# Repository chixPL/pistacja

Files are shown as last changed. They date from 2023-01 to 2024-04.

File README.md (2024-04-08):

# Pistacja
## A web-based weather station built with Raspberry Pi and Python.

<p align="center">
    pistacja-logo
</p>

🇵🇱 Wersja po polsku jest dostepna [tutaj](../master/README_pl.md).

*The name is a wordplay in Polish - Pi because it's built with Raspberry Pi and stacja (station). Together they make pistachio.*

## Features
* Current weather conditions (temperature, wind speed anddirection, humidity, pressure, etc.)
* History of the weather at given dates
* Statistical data - charts and graphs for the weather this week and this month
* Server info: Neofetch, uptime

Loosely based on [this guide](https://projects.raspberrypi.org/en/projects/build-your-own-weather-station/0), however due to hardware differences I wrote a lot of the code myself.

## Requirements
* Raspberry Pi (tested on Model 3 B V1.2). Internet connection required.
* Latest version of Raspbian with Python 3.7+ installed
* MCP3008 ADC converter
* Two Ethernet outlets or breakout boards
* Barometer and altimeter (built with Pololu LPS25H)
* Anemometer, rain gauge (built with SparkFun Weather Meter Kit)
* Temperature and humidity sensor (built with Aosong AM2301)
* 4.7kΩ resistor

## Installation
1. Build the weather station according to the schema below.
2. Clone this repository to your Raspberry Pi
3. Enable I2C and SPI in `raspi-config`. Reboot.
4. Install the required Python packages: `pip3 install -r requirements.txt`
5. Set the database config in .db to point to an external server
6. Run the server: `python3 main.py`
7. Paste the frontend directory to your web server's root directory and set db_connect.php to point to the same server
8. Open the website in your browser and enjoy!

### Build schematic
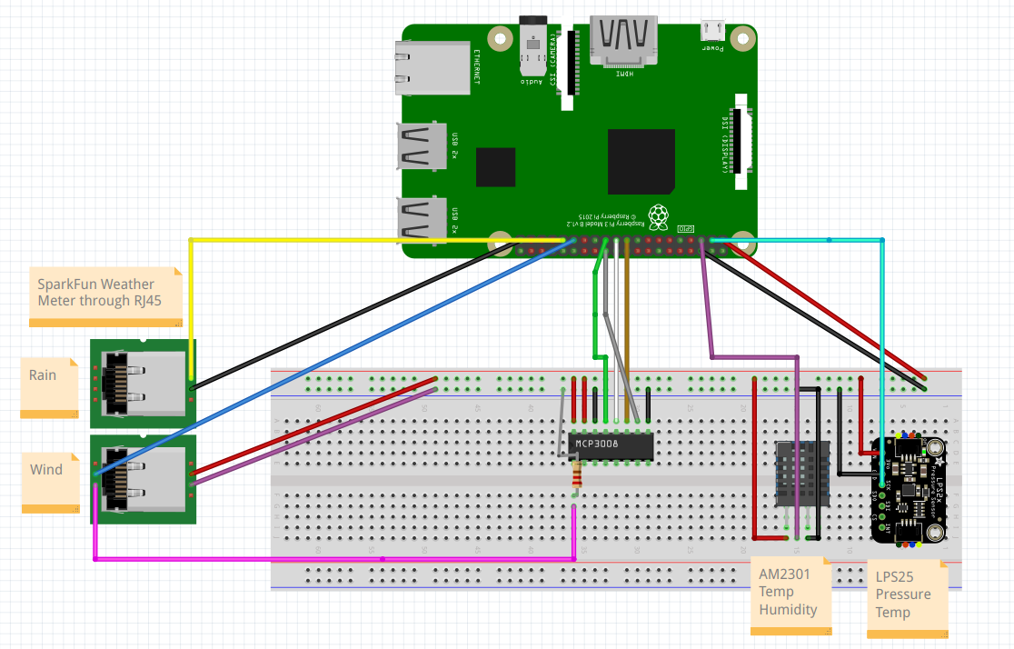
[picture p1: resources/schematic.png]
schematic


## Screenshots
### Build
#### Without case
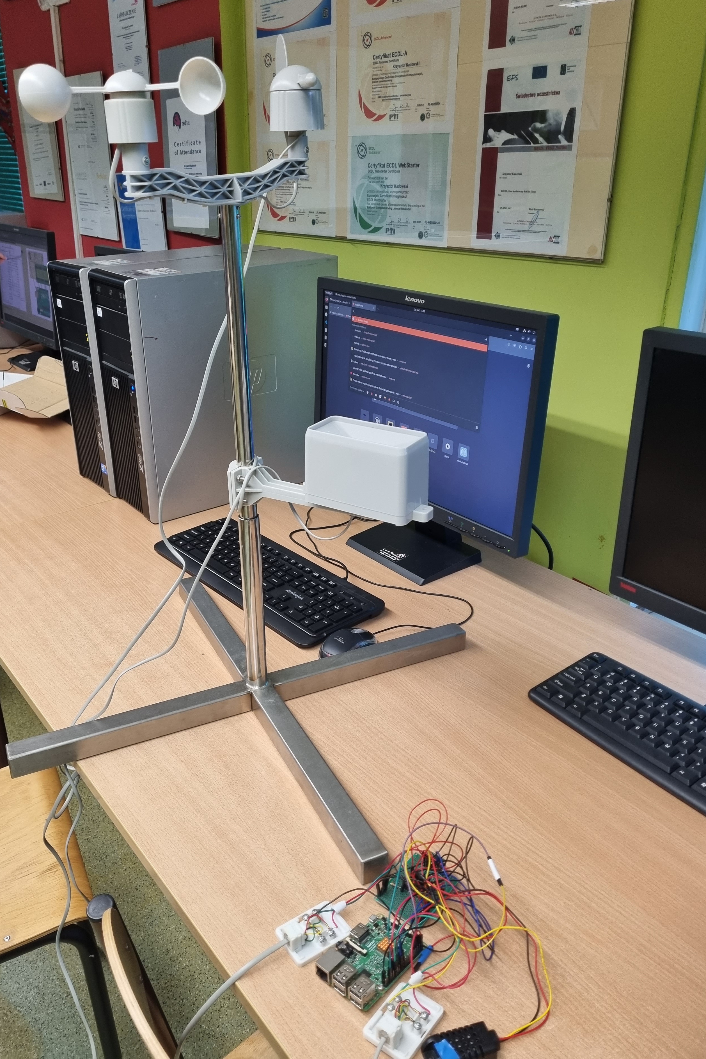
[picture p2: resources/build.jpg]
build-nocase

When properly laid out, the case dimensions would be around 17x15x7cm. I left enough wiggle room to account for longer wires and/or nonstandard peripherals
#### With case
[TBD]

### Backend
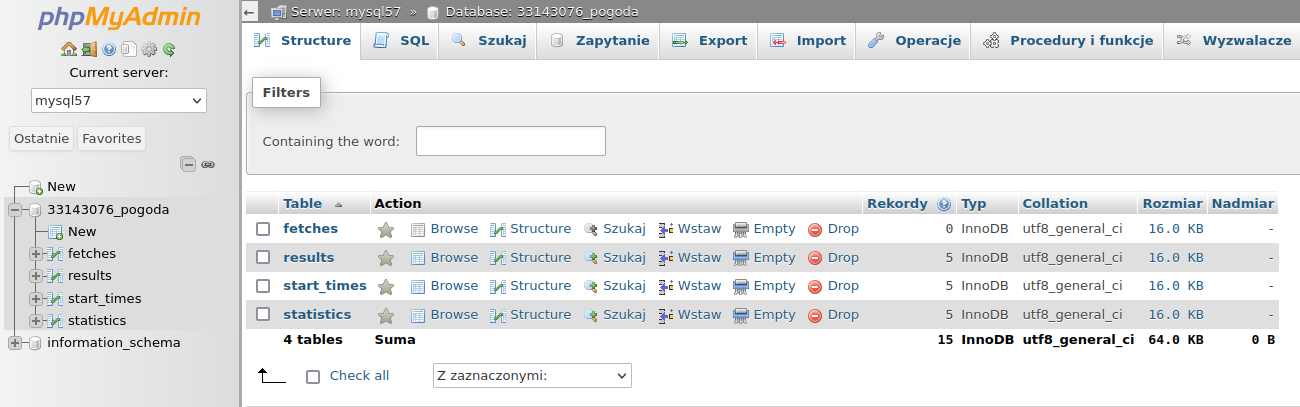
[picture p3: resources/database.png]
database

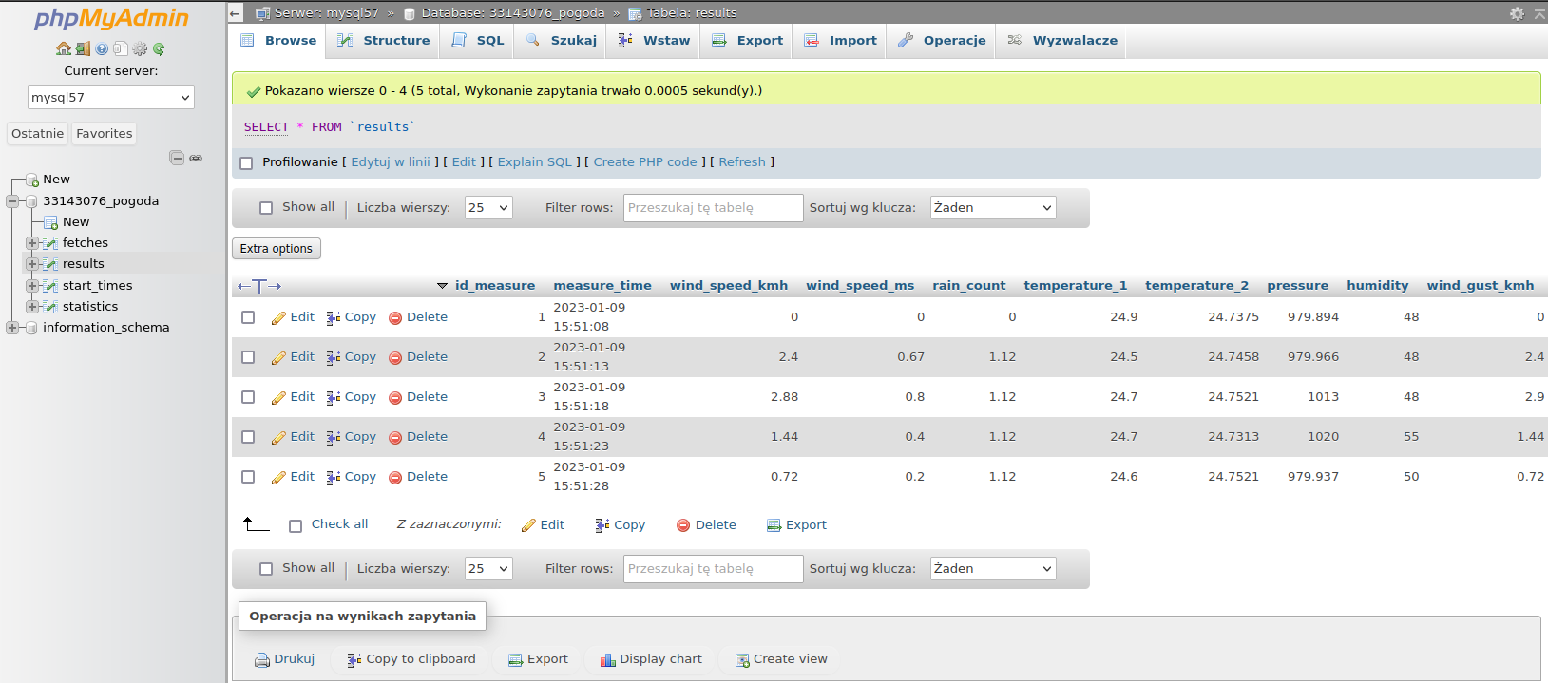
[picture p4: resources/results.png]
results


### Frontend
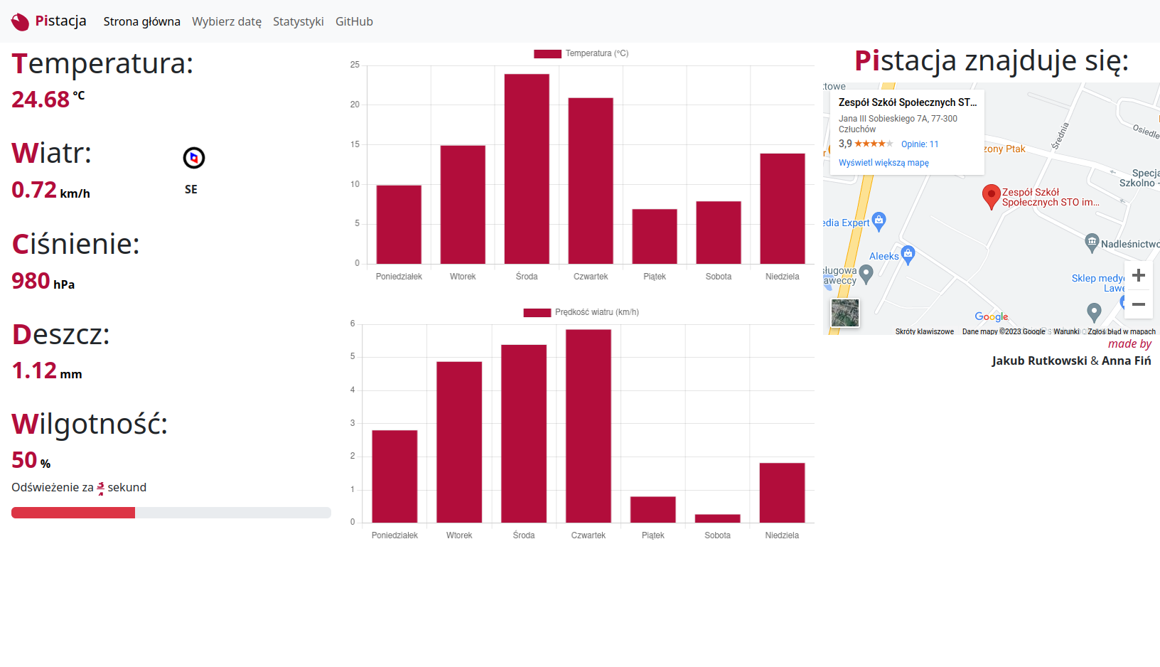
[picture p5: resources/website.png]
website


## License and Credits
This project is licensed under the GPLv3 license - see the LICENSE.md file for details.
Thanks to the Raspberry Pi Foundation for the guide.
Schematics made in Fritzing.

Made by Jakub Rutkowski (x5px) 2023

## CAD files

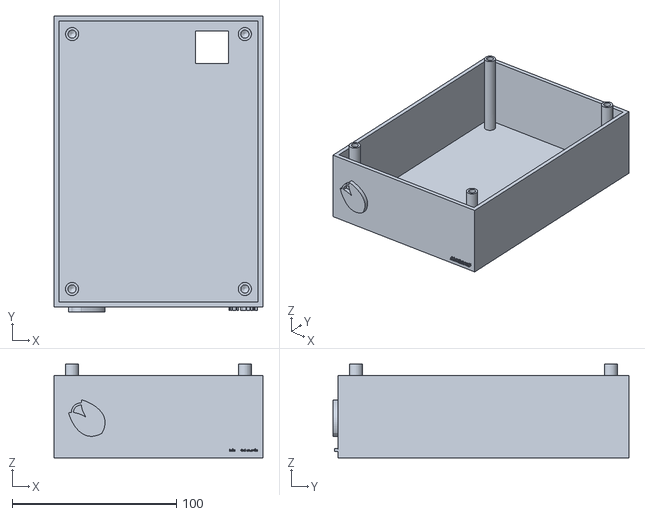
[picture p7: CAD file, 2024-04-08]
Model 3D/STL/Pistacja.stl
127.0 x 180.0 x 57.0

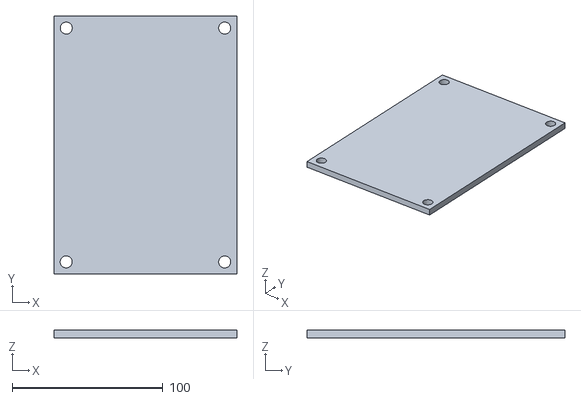
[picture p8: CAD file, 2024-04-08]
Model 3D/STL/Pistacja Wieko.stl
121.0 x 171.0 x 5.00

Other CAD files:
Model 3D/Fusion360/Pistacja Wieko.f3d
Model 3D/Fusion360/Pistacja.f3d

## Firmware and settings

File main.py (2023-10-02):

"""
[PL]
Pistacja - stacja pogodowa za pomocą Raspberry Pi
[EN]
Pistacja - a weather station with Raspberry Pi

Losto 2022
by: Jakub Rutkowski & Ania Fiń
[EN]
"""

# Standard imports
import math
import time
import atexit
import statistics

# Requirements (pip install -r requirements.txt)
import board
from gpiozero import Button, MCP3008 # Button (on/off signal detector) - Sparkfun Weather Meter, MCP3008 - ADC converter
import adafruit_dht # Barometer, altimeter
import adafruit_lps2x # Temperature and humidity
import psutil # Process manager
from apscheduler.schedulers.background import BackgroundScheduler # Threading
import mysql.connector # SQL database
from config import config # SQL database config

# Fixes DHT library on second run. For some reason the event listener doesn't close properly.
for proc in psutil.process_iter():
    if proc.name() == 'libgpiod_pulsein' or proc.name() == 'libgpiod_pulsei':
        proc.kill()

results = {} # Current results
results_old = {} # Past results, ensures that the database is filled even if DHT errors out. 
# DHT timeouts are a frequent occurence due to how the tech is implemented on the manufacturer's side.

class Wind():
    # Count (speed)
    dev_wind_sensor = Button(5) # GPIO port 5
    wind_interval = 5 # Refresh every 5 seconds
    windcount = 0
    
    # Direction
    adc = MCP3008(channel=0)
    count = 0
    values = []
    volts = {0.4: 0.0,
             1.4: 22.5,
             1.2: 45.0,
             2.8: 67.5,
             2.7: 90.0,
             2.9: 112.5,
             2.2: 135.0,
             2.5: 157.5,
             1.8: 180.0,
             2.0: 202.5,
             0.7: 225.0,
             0.8: 247.5,
             0.1: 270.0,
             0.3: 292.5,
             0.2: 315.0,
             0.6: 337.5} # Static values for converting voltage to degrees. See guide in README

    def spin(self):
        self.windcount += 1
        #print("spin "+str(count))

    def cmsToKmh(self, speed):
        # The wind speed is by default measured in centimeters per second. 
        # To make it make sense to the end user, we convert it to kilometers per hour.
        # You could probably convert to miles as well if you're American.
        
        cm_w_km = 100000.0 # Centimeters in a kilometer
        sek_w_godz = 3600 # Seconds in an hour
        
        km_na_sek = speed / cm_w_km
        km_na_godz = km_na_sek * sek_w_godz
        
        return km_na_godz

    def cmsToMs(self, speed): # Centimeters per second to meters per second
        return speed / 100

    def calibrate(self, speed):
        return speed*1.18 # Correction factor for the wind sensor, See guide in README

    def reset_wind(self):
        self.windcount = 0

    def calculate_speed(self):
        """"
        
        Speed calculation: V = S / t
        We're calculating the speed of the wind by dividing the distance traveled by the time it took to travel it.
        The distance is calculated by multiplying the circumference of the wind sensor by the number of rotations within the timeframe (5 seconds).
    
        The radius of the main anemometer is different for each sensor, so you'll have to measure it yourself.
        For SparkFun, it is 9 cm.
           
        """
        self.store_speeds_kmh = []
        self.store_speeds_ms = []

        radius_cm = 9.0
        circumference_cm = (2 * math.pi) * radius_cm
        rotations = self.windcount / 2.0
        dist_cm = circumference_cm * rotations
        speed = dist_cm / self.wind_interval 
        
        return (round(self.cmsToKmh(self.calibrate(speed)), 2), round(self.cmsToMs(self.calibrate(speed)), 2))
    
    def wind_count(self):
        self.dev_wind_sensor.when_pressed = self.spin
    
        final_speed_kmh = self.calculate_speed()[0] # Get average speed in 5 second interval (km/h)
        final_speed_ms = self.calculate_speed()[1] # Get average speed in 5 second interval (m/s)
        self.store_speeds_kmh.append(final_speed_kmh)
        self.store_speeds_ms.append(final_speed_ms)
    
        # Wind gusts are the highest speeds in a 5 second interval.
        # Wind speed is the mean speed in a 5 second interval.
        results['wind_gust_kmh'] = round(max(self.store_speeds_kmh), 2)
        results['wind_gust_ms'] = round(max(self.store_speeds_ms), 2)
        
        results['wind_speed_kmh'] = round(statistics.mean(self.store_speeds_kmh), 2)
        results['wind_speed_ms'] = round(statistics.mean(self.store_speeds_ms), 2)
    
    def get_average(self, angles):
        """
        Get the average of a number of angles.
        The weather station returns them in radians, so we have to convert them to degrees.
        To calculate the average, we calculate the arcus tangens of the sum of the sines divided by the sum of the cosines.
        Read more at https://en.wikipedia.org/wiki/Directional_statistics.
        Then we convert the result to a range of 0-360 degrees.
        """
        sin_sum = 0.0
        cos_sum = 0.0

        for angle in angles:
            r = math.radians(angle)
            sin_sum += math.sin(r)
            cos_sum += math.cos(r)

        flen = float(len(angles))
        try:
            s = sin_sum / flen
            c = cos_sum / flen
        except ZeroDivisionError:
            s = 0
            c = 0
        
        arc = math.degrees(math.atan(s / c))
        average = 0.0

        if s > 0 and c > 0:
            average = arc
        elif c < 0:
            average = arc + 180
        elif s < 0 and c > 0:
            average = arc + 360

        return 0.0 if average == 360 else average
    

    def wind_direction(self):
        data = []
        wind = round(self.adc.value*3.3, 1) # Get voltage from ADC converter
        # The datasheet assumes 10k ohms for a 5V rail, but the Raspberry Pi's GPIO rail is 3.3V.
        # We have to adjust the values accordingly.
        if not wind in self.volts:
            pass
            #print("Unknown value" + str(wind))
        else:
            data.append(self.volts[wind])

        results['wind_direction'] = self.get_average(data)
    
    def post(self): # Start the sensors
        self.wind_count()
        self.reset_wind()
        self.wind_direction()

class Rain():
    dev_rain_sensor = Button(6) # GPIO 6
    rain_count = 0
    bucket_size = 0.2794 # Size of the bucket. Differs from model to model.
        
    def raincount(self):
        self.dev_rain_sensor.when_pressed = self.tip
    
    def tip(self):
        self.rain_count += 1
        results['rain_count'] = round(self.rain_count * self.bucket_size, 2)

    def reset_rainfall(self): # Reset rainfall every hour
        self.rain_count = 0
        
    def post(self): # Start the sensors
        self.raincount()    

class ActiveSensors():
    dev_temp_humi_sensor = adafruit_dht.DHT21(board.D4) # GPIO port 4
    dev_i2c = board.I2C() # I2C has to be enabled in raspi-config for this to work!
    dev_lps = adafruit_lps2x.LPS25(dev_i2c) # Port 2 - clock, port 3 - data
    
    def temp_humi_sensor(self):
        try:
            # Print the values to the serial port
            temperature = self.dev_temp_humi_sensor.temperature
            humidity = self.dev_temp_humi_sensor.humidity
            results['temperature_1'] = temperature
            results['humidity'] = humidity
        except RuntimeError as error:
            # Errors happen fairly often, DHT's are hard to read, just keep going
            print(error.args[0])
            time.sleep(2.0)
        except Exception as error:
            self.dev_temp_humi_sensor.exit()
            # Raise error
            time.sleep(2.0)
    
    def pressure_sensor(self):
        results['pressure'] = self.dev_lps.pressure
        results['temperature_2'] = self.dev_lps.temperature

    def post(self):
        self.temp_humi_sensor()
        self.pressure_sensor()
        
class SQLDatabase:
    
    def __init__(self):
        try:
            params = config() # Load connection parameters from config.py
            self.conn = mysql.connector.connect(**params)       
        except (Exception, mysql.connector.DatabaseError) as err: # Catch errors
            print(f"Błąd połączenia z bazą: {err}")
        
    def execute(self, sql):
        self.cur = self.conn.cursor()
        self.cur.execute(sql)
        self.conn.commit()
        
    def close_conn(self):
        self.cur.close()
        self.conn.close() # Close connection to database
       

# Driver code

print("=" * 20)
print("Pistacja is active!")
print("Made by Jakub Rutkowski & Ania Fiń 2022-2023")
print("=" * 20)

# Initialize classes
wind = Wind()
rain = Rain()
act = ActiveSensors()

# Threading
sched = BackgroundScheduler(job_defaults={'max_instances': 6})
sched.add_job(wind.post, 'interval', seconds=5)
sched.add_job(rain.post, 'interval', seconds=5)
sched.add_job(act.post, 'interval', seconds=5)
sched.add_job(rain.reset_rainfall, 'interval', hours=1)
sched.start()

db = SQLDatabase() # Connect to database
atexit.register(db.close_conn) # Close connection to database on exit
db.execute("INSERT INTO start_times VALUES(CURRENT_TIMESTAMP()") # Save start time to database, for uptime

while(True):
    time.sleep(5)
    results = results_old | results # Overwrite all old values with new ones
    db.execute(f"INSERT INTO results(wind_speed_kmh, wind_speed_ms, rain_count, temperature_1, temperature_2, pressure, humidity, wind_gust_kmh, wind_gust_ms) VALUES({results['wind_speed_kmh']}, {results['wind_speed_ms']}, {results['rain_count']}, {results['temperature_1']}, {results['temperature_2']}, {results['pressure']}, {results['humidity']}, {results['wind_gust_kmh']}, {results['wind_gust_ms']})")
    #print(f"INSERT INTO results(wind_speed_kmh, wind_speed_ms, rain_count, temperature_1, temperature_2, pressure, humidity, wind_gust_kmh, wind_gust_ms) VALUES({results['wind_speed_kmh']}, {results['wind_speed_ms']}, {results['rain_count']}, {results['temperature_1']}, {results['temperature_2']}, {results['pressure']}, {results['humidity']}, {results['wind_gust_kmh']}, {results['wind_gust_ms']})")
    results_old = results

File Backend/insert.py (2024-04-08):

# Wstawianie rekordów do tabel
from click import command
import psycopg2
from config import config

def insert_address(address1, address2, city):
    command = """
            INSERT INTO address(address1, address2, city)
            VALUES(%s, %s, %s) RETURNING id_address;
    """
    
    conn = None
    id_address = None
    
    try:
        params = config()
        conn = psycopg2.connect(**params)
        cur = conn.cursor()
        cur.execute(command, (address1, address2, city))
        id_address = cur.fetchone()[0]
        
        cur.close()
        conn.commit()                       #zatwierdzanie wykonania komendy
    except (Exception, psycopg2.DatabaseError) as err:
        print(f"Błąd bazy: {err}")
    
    finally:
        if conn is not None:
            conn.close() 
        print(f"Wstawienie rekordu o id= {id_address} zakończono... ")

def insert_address_list(address_list):
    command = """
            INSERT INTO address(address1, address2, city)
            VALUES(%s, %s, %s);
    """
    conn = None
    id_address = None
    
    try:
        params = config()
        conn = psycopg2.connect(**params)
        cur = conn.cursor()
        print(address_list)
        
        for add in address_list:       
            cur.execute(command, (str(add[0]), str(add[1]), str(add[2])))
        
        cur.close()
        conn.commit()                       #zatwierdzanie wykonania komendy
    except (Exception, psycopg2.DatabaseError) as err:
        print(f"Błąd bazy: {err}")
    
    finally:
        if conn is not None:
            conn.close() 
        print(f"Wstawienie rekordów zakończono... ")


if __name__ == '__main__':
    insert_address("Długa", "23", "Warszawa") 
    
    insert_address_list([
        ("Średnia", "17", "Warszawa"),
        ("Krótka", "2A", "Gdańsk"),
        ("Długa", "13", "Kraków"),
        ]) 

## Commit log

2023-01-15 Naprawa timera
2023-03-19 drobne techniczne, refactor if/else do switcha
2023-10-16 Fritzing schematics
    [schematic.fzz]
2023-10-30 Case build: step 1
2024-04-08 Refactor folderów, modele 3D
    [Pistacja Wieko.f3d, Pistacja Wieko.stl, Pistacja.f3d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]
2024-04-08 Usunięcie starych plików
    [schematic.fzz]
